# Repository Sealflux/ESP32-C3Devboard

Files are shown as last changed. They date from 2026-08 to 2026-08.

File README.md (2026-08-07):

# ESP32-C3Devboard
## Description
Custom ESP32-C3 Devboard with bulit in charging, wifi and antenna.
## Features
- ESP32-C3 which has wifi capabilities along with bulit in charging for lipo battery.
- 16 MB of onboard flash storage
- Charges through USB-C
- Tactile button to reset.
## Hardware
- ESP32-C3
- BLE Wifi
- Battery Charging
- Lots and lots of capacitors and resistors

# Bill Of Materials (BOM)
| Designator | Part | Qty | Cost (each) | Total | Link | LCSC # |
|---|---|:---:|---|---|---|---|
| BT1 | Battery Cell | 1 | Depends on battery | Depends on battery | Depends on battery | N/A |
| C1, C5, C6, C7 | 100nF Capacitor (0402) | 4 |$0.0073|$0.73| [LCSC](https://lcsc.com/product-detail/C60474.html) | C60474 |
| C2, C3, C4, C9 | 10µF Capacitor (0603) | 4 |$0.0411|$0.82| [LCSC](https://lcsc.com/product-detail/C85713.html) | C85713 |
| C8 | 1µF Capacitor (0603) | 1 |$0.0225|$1.13| [LCSC](https://lcsc.com/product-detail/C29936.html) | C29936 |
| J1 | USB-C Receptacle USB2.0 14P | 1 |$0.1709|$0.1709| [LCSC](https://www.lcsc.com/product-detail/C165948.html) | C165948 |
| J2, J3 | 1x12 Pin Header (2.54mm) | 2 |N/A|Generic, use whatever you want.| N/A | N/A |
| R1, R11 | 1kΩ Resistor (0603) | 2 |$0.0045|0.45 | [LCSC](https://lcsc.com/product-detail/C2907002.html) | C2907002 |
| R2, R8, R9, R10 | 10kΩ Resistor (0402) | 4 |$0.0038|0.38| [LCSC](https://lcsc.com/product-detail/C60490.html) | C60490 |
| R3, R4 | 5.1kΩ Resistor (0603) | 2 |$0.0027|0.27| [LCSC](https://lcsc.com/product-detail/C2907044.html) | C2907044 |
| R6 | 2.2kΩ Resistor (0402) | 1 |$0.0024|$0.24| [LCSC](https://lcsc.com/product-detail/C2906865.html) | C2906865 |
| SW1, SW2 | Push Button Switch (B3U-1000PM) | 2 |$0.1869|$0.93|[LCSC](https://www.lcsc.com/product-detail/C231329.html)| C231329 |
| U1 | ESP32-C3 (QFN-32) | 1 |N/A|Depends on where you buy from|[Datasheet](https://www.espressif.com/sites/default/files/documentation/esp32-c3_datasheet_en.pdf) | N/A |
| U2 | W25Q16JVUXIQ (USON-8) | 1 |$1.6193|$1.6193| [LCSC](https://lcsc.com/product-detail/C2843335.html) | C2843335 |
| U3 | H7233-1 LDO (SOT-23-3) | 1 |$0.1102|$0.55| [LCSC](https://lcsc.com/product-detail/C277859.html) | C277859 |
| U4 | TP4056 Battery Charger (ESOP-8) | 1 |$0.1864|$0.93 | [LCSC](https://lcsc.com/product-detail/C16581.html) | C16581 |
| | **Shipping** | | | Depends on your address | | |
| | **Total Costs** | | | Without shipping | | |

## Steps To Reproduce
1. Download the gerbers.zip from production folder
2. Manufacture the PCBs from whatever manufacturer you want using the gerbers.zip
3. Order the components from BOM
4. Solder the components onto the PCBs
5. Enjoy your dev board!
## Schematic

## PCB

## PCBA


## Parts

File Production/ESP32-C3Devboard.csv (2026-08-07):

Reference | Qty | Value | DNP | Exclude from BOM | Exclude from Board | Footprint | Datasheet
BT1 | 1 | Battery_Cell |  |  |  | Connector_PinHeader_2.54mm:PinHeader_1x02_P2.54mm_Vertical
C1,C5,C6,C7 | 4 | 100nF |  |  |  | easyeda2kicad:C0402 | https://lcsc.com/product-detail/Multilayer-Ceramic-Capacitors-MLCC-SMD-SMT_100nF-104-10-16V_C60474.html
C2,C3,C4,C9 | 4 | 10uF |  |  |  | easyeda2kicad:C0603 | https://lcsc.com/product-detail/Multilayer-Ceramic-Capacitors-MLCC-SMD-SMT_SAMSUNG_CL10A106MP8NNN_10uF-106-20-10V_C85713.html
C8 | 1 | 1uF |  |  |  | easyeda2kicad:C0603 | https://lcsc.com/product-detail/Multilayer-Ceramic-Capacitors-MLCC-SMD-SMT_SAMSUNG_CL10B105KA8NNNC_1uF-105-10-25V-X7R_C29936.html
J1 | 1 | USB_C_Receptacle_USB2.0_14P |  |  |  | Connector_USB:USB_C_Receptacle_HRO_TYPE-C-31-M-12 | https://www.usb.org/sites/default/files/documents/usb_type-c.zip
J2,J3 | 2 | Conn_01x12 |  |  |  | Connector_PinHeader_2.54mm:PinHeader_1x12_P2.54mm_Vertical
R1,R11 | 2 | 1kΩ |  |  |  | easyeda2kicad:R0603 | https://www.lcsc.com/datasheet/C2907002.pdf
R2,R8,R9,R10 | 4 | 10kΩ |  |  |  | easyeda2kicad:R0402 | https://lcsc.com/product-detail/Chip-Resistor-Surface-Mount_10KR-1002-1_C60490.html
R3,R4 | 2 | 5.1kΩ |  |  |  | easyeda2kicad:R0603 | https://www.lcsc.com/datasheet/C2907044.pdf
R6 | 1 | 2.2kΩ |  |  |  | easyeda2kicad:R0402 | https://www.lcsc.com/datasheet/C2906865.pdf
SW1,SW2 | 2 | SW_Push |  |  |  | easyeda2kicad:KEY-SMD_B3U-1000PM
U1 | 1 | ESP32-C3 |  |  |  | Package_DFN_QFN:QFN-32-1EP_5x5mm_P0.5mm_EP3.7x3.7mm | https://www.espressif.com/sites/default/files/documentation/esp32-c3_datasheet_en.pdf
U2 | 1 | W25Q16JVUXIQ |  |  |  | easyeda2kicad:USON-8_L3.0-W2.0-P0.50-BL-EP | https://www.lcsc.com/datasheet/C2843335.pdf
U3 | 1 | H7233-1_C277859 |  |  |  | easyeda2kicad:SOT-23-3_L2.9-W1.3-P1.90-LS2.4-BR | https://lcsc.com/product-detail/Low-Dropout-Regulators-LDO_Shanghai-Siproin-Microelectronics-H7233-1_C277859.html
U4 | 1 | TP4056 |  |  |  | easyeda2kicad:ESOP-8_L4.9-W3.9-P1.27-LS6.0-BL-EP | https://lcsc.com/product-detail/PMIC-Battery-Management_TP4056_C16581.html

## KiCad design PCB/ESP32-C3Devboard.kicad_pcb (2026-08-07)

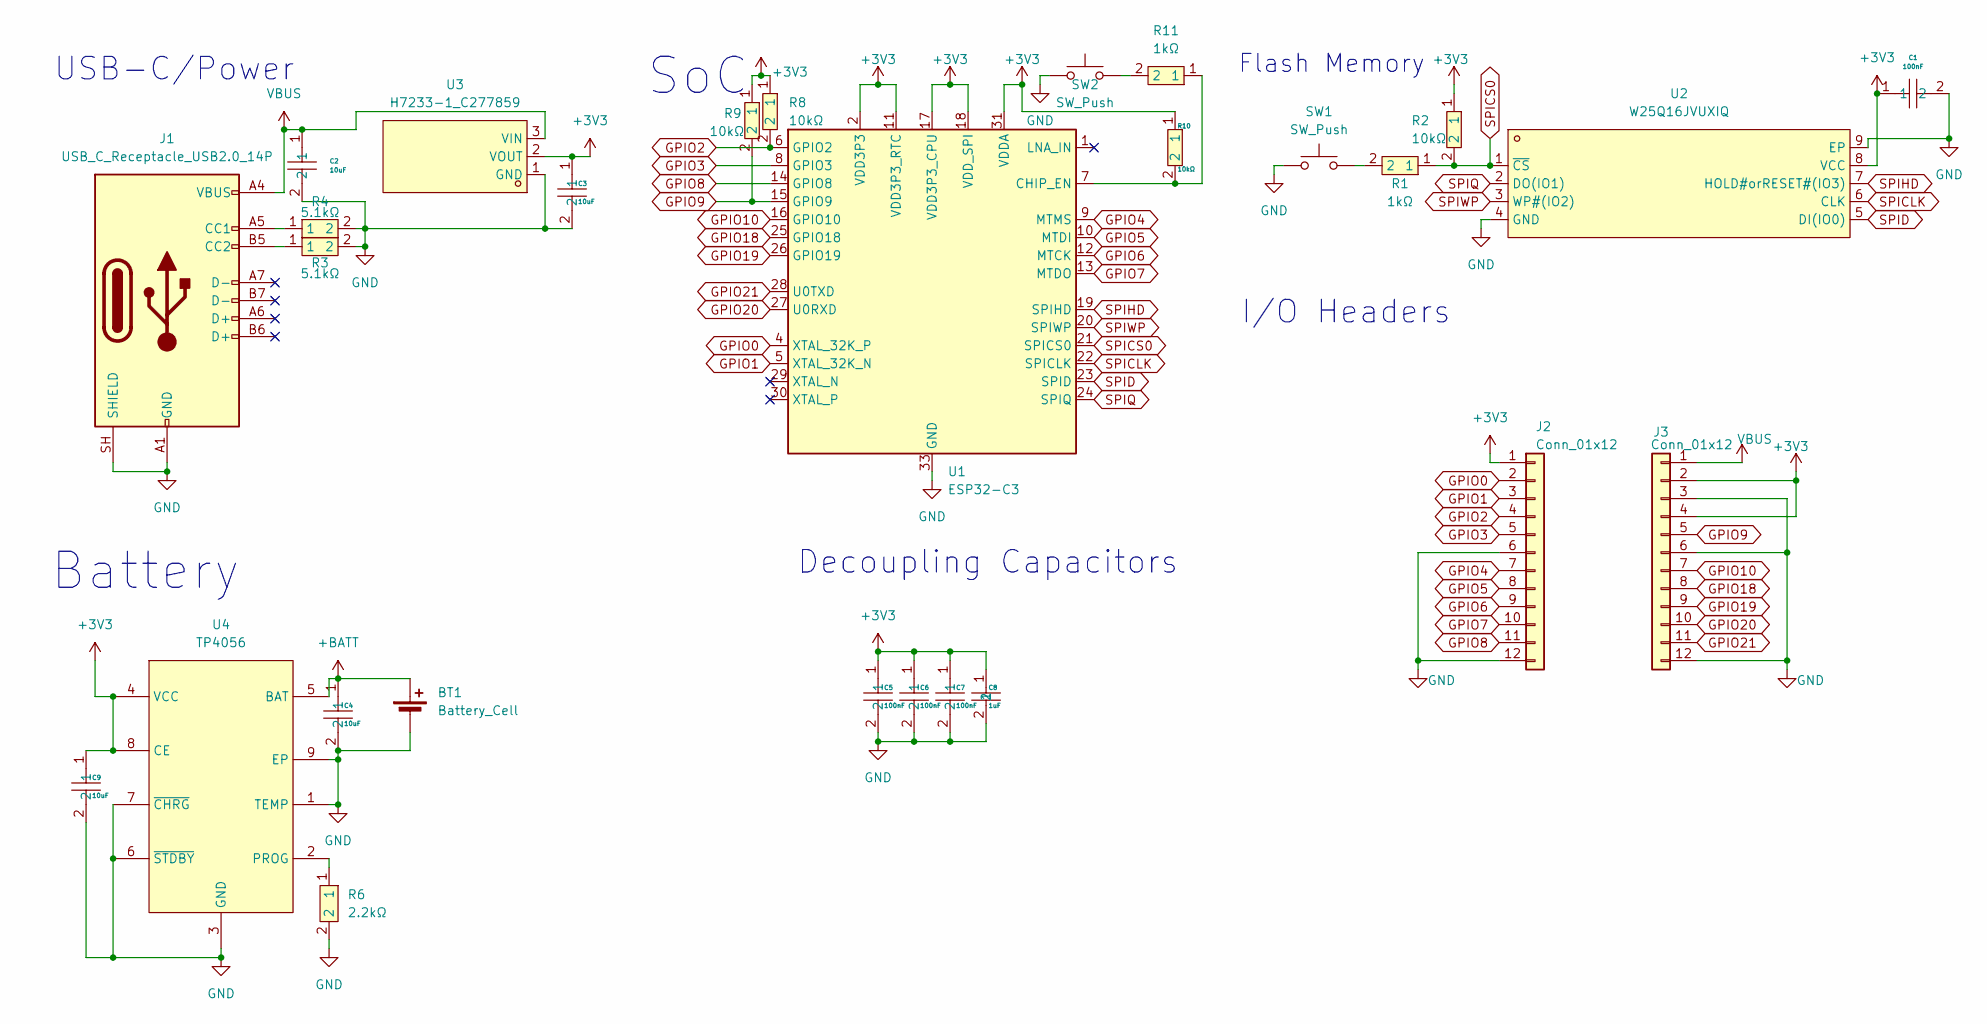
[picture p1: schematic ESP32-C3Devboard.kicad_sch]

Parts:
BT1: Battery_Cell; PinHeader_1x02_P2.54mm_Vertical
C1, C5, C6, C7: 100nF; C0402; MPN CC0402KRX7R7BB104; LCSC Part C60474
C2, C3, C4, C9: 10uF; C0603; MPN CL10A106MP8NNNC; LCSC Part C85713
C8: 1uF; C0603; MPN CL10B105KA8NNNC; LCSC Part C29936
J1: USB_C_Receptacle_USB2.0_14P; USB_C_Receptacle_HRO_TYPE-C-31-M-12
J2, J3: Conn_01x12; PinHeader_1x12_P2.54mm_Vertical
R1, R11: 1kΩ; R0603; MPN FRC0603F1001TS; LCSC Part C2907002
R2, R8, R9, R10: 10kΩ; R0402; MPN RC0402FR-0710KL; LCSC Part C60490
R3, R4: 5.1kΩ; R0603; MPN FRC0603F5101TS; LCSC Part C2907044
R6: 2.2kΩ; R0402; MPN FRC0402F2201TS; LCSC Part C2906865
SW1, SW2: SW_Push; KEY-SMD_B3U-1000PM
U1: ESP32-C3; QFN-32-1EP_5x5mm_P0.5mm_EP3.7x3.7mm
U2: W25Q16JVUXIQ; USON-8_L3.0-W2.0-P0.50-BL-EP; MPN W25Q16JVUXIQ; LCSC Part C2843335
U3: H7233-1_C277859; SOT-23-3_L2.9-W1.3-P1.90-LS2.4-BR; MPN H7233-1; LCSC Part C277859
U4: TP4056; ESOP-8_L4.9-W3.9-P1.27-LS6.0-BL-EP; MPN TP4056-42-ESOP8; LCSC Part C16581

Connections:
+3V3: C1.1, C3.1, C5.1, C6.1, C7.1, C8.1, C9.1, J2.1, J3.2, J3.4, R2.1, R8.1, R9.1, R10.1, U1.2 (VDD3P3), U1.3 (VDD3P3), U1.11 (VDD3P3_RTC), U1.17 (VDD3P3_CPU), U1.18 (VDD_SPI), U1.31 (VDDA), U1.32 (VDDA), U2.8 (VCC), U3.2 (VOUT), U4.4 (VCC), U4.8 (CE); also elsewhere on the board
+BATT: BT1.1 (+), C4.1, U4.5 (BAT)
GND: BT1.2 (-), C1.2, C2.2, C3.2, C4.2, C5.2, C6.2, C7.2, C8.2, C9.2, J1.A1 (GND), J1.A12 (GND), J1.B1 (GND), J1.B12 (GND), J1.SH (SHIELD), J2.6, J2.12, J3.3, J3.6, J3.12, R3.2, R4.2, R6.2, SW1.1, SW2.1, U1.33 (GND), U2.4 (GND), U2.9 (EP), U3.1 (GND), U4.1 (TEMP), U4.3 (GND), U4.6 (~STDBY), U4.7 (~CHRG), U4.9 (EP); also elsewhere on the board
GPIO0: J2.2, U1.4 (XTAL_32K_P)
GPIO1: J2.3, U1.5 (XTAL_32K_N)
GPIO2: J2.4, R8.2, U1.6 (GPIO2)
GPIO3: J2.5, U1.8 (GPIO3)
GPIO4: J2.7, U1.9 (MTMS)
GPIO5: J2.8, U1.10 (MTDI)
GPIO6: J2.9, U1.12 (MTCK)
GPIO7: J2.10, U1.13 (MTDO)
GPIO8: J2.11, U1.14 (GPIO8)
GPIO9: J3.5, R9.2, U1.15 (GPIO9)
GPIO10: J3.7, U1.16 (GPIO10)
GPIO18: J3.8, U1.25 (GPIO18)
GPIO19: J3.9, U1.26 (GPIO19)
GPIO20: J3.10, U1.27 (U0RXD)
GPIO21: J3.11, U1.28 (U0TXD)
unnamed: J1.A5 (CC1), R4.1
unnamed: J1.B5 (CC2), R3.1
unnamed: R1.2, SW1.2
unnamed: R11.2, SW2.2
unnamed: R10.2, R11.1, U1.7 (CHIP_EN)
unnamed: R6.1, U4.2 (PROG)
SPICLK: U1.22 (SPICLK), U2.6 (CLK)
SPICS0: R1.1, R2.2, U1.21 (SPICS0), U2.1 (~CS)
SPID: U1.23 (SPID), U2.5 (DI(IO0))
SPIHD: U1.19 (SPIHD), U2.7 (HOLD#orRESET#(IO3))
SPIQ: U1.24 (SPIQ), U2.2 (DO(IO1))
SPIWP: U1.20 (SPIWP), U2.3 (WP#(IO2))
VBUS: C2.1, J1.A4 (VBUS), J1.A9 (VBUS), J1.B4 (VBUS), J1.B9 (VBUS), J3.1, U3.3 (VIN)

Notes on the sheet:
Decoupling Capacitors
Flash Memory
I/O Headers
SoC
Battery
USB-C/Power

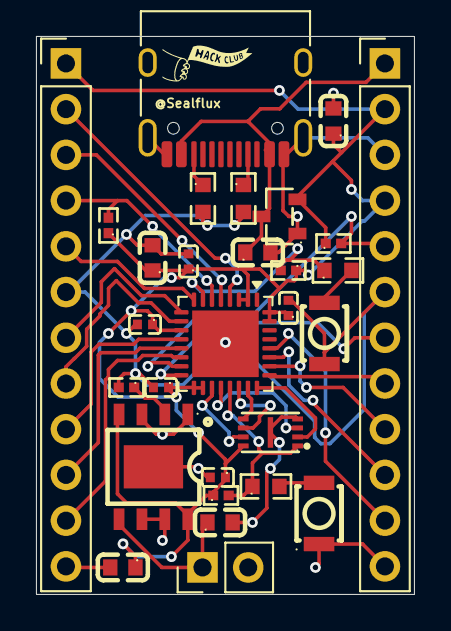
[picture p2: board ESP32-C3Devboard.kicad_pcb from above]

Board: 2 copper layers, 21.0 x 31.0 mm, 29 parts (0 on the bottom side), 31 nets.

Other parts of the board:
C8#2: 1uF; C0603

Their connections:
+3V3: C8#2.1; also elsewhere on the board
GND: C8#2.2; also elsewhere on the board

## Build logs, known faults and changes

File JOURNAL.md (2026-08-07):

## August 2nd: Beginning the project!
I'll be using the ESP32-C3 developed by expressif as the MCU/brains of this devboard!
I began researching the datasheet and forgot that I had something to do. I quickly installed flash memory for the esp32-c3 using a quad spi module while also adding a button for setting cs to low and adding decoupling capacitor for the Power of the fash memory. 
Current Schematic:
### Lapse Link: https://lapse.hackclub.com/timelapse/lOYapriT_lcY

## August 3rd: Adding USB along with battery
I added a USB C Receptacle along with starting to implement battery charging but I don't think its done yet. It was a pain to go through all of the datasheets and understand each component and wiring them but it is what it is..
Current Schematic: 
### Lapse Link: https://lapse.hackclub.com/timelapse/0mVoWRxlGfGC

## August 4th: Adding pull up resistorsa and EN reset button
Went through the datasheet again and realized that certain pins needed to be pulled up along with the CHIP_EN being pulled high or low turning off the chip so I made that into a button.
Current Schematic:

### Lapse Link: https://lapse.hackclub.com/timelapse/Z4B6Hk9UXLxQ

## August 4th: Adding IO Headers to Schematic
Started adding IO Headers to schematic and began using the global labels from looking at the datasheet.
### Lapse Link: https://lapse.hackclub.com/timelapse/oeQ2Q57TR_s_

## August 5th-6th: Finishing the PCB hopefully
I will begin wiring and assigning the global labels to the IO Headers. So I started doing that along with adding LED indicators to the Battery section.
### Lapse Link: https://lapse.hackclub.com/timelapse/X9MPH5Bhr9M_

## August 7th: Finishing the PCB hopefully without any delays
I started by assigning footprints to the corresponding components. I began doing all of the traces and realized that flashing through USB wouldn't be the best idea since due to the limited space on the edge cuts. So if you want to flash the devboard, you must do so over wifi rather than USB. I finally fixed up all of the errors and now I just need to add silkscreen final touches and I can submit!
Final Schematic:
Final PCB:
Final PCBA:
### Lapse Link: https://lapse.hackclub.com/timelapse/7NjPehKcUoc7

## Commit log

2026-08-03 ## August 3rd: Adding USB along with battery
2026-08-04 ## August 4th: Adding pull up resistorsa and EN reset button
2026-08-05 ## August 4th: Adding IO Headers to Schematic
2026-08-07 ## August 7th: Finishing the PCB hopefully without any delays
    [ESP32-C3Devboard.csv, ESP32-C3Devboard.kicad_pcb, ESP32-C3Devboard.kicad_sch]
